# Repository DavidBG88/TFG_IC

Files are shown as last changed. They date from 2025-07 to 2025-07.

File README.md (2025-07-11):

# SIDCMOCS  
**Sistema Inteligente Distribuido de Control y Monitorización para la Optimización de Cultivos Sostenibles sobre una Arquitectura Edge-IoT basada en ESP32**

## Descripción

Este proyecto desarrolla **SIDCMOCS**, una solución modular y económica diseñada para automatizar el control climático de invernaderos mediante tecnologías abiertas. El sistema utiliza microcontroladores ESP32 en una arquitectura distribuida IoT para monitorizar variables ambientales y activar actuadores en función de las condiciones detectadas.

Entre sus funcionalidades destacan:

- Monitorización de temperatura, humedad, iluminación, calidad del aire y condiciones del suelo.
- Activación automática de ventiladores, luces LED y sistemas de riego.
- Comunicación distribuida mediante MQTT.
- Visualización remota con Grafana Cloud y alertas vía bot de Telegram.
- Almacenamiento local en tarjetas microSD y backend con Node.js y MySQL.
- Análisis de datos con Python y generación de gráficas.

El sistema ha sido validado mediante una maqueta funcional en un entorno doméstico controlado.

## Estructura del repositorio

- Codigo/ # Código fuente para ESP32 (C++), dividido en nodo maestro y esclavos, pruebas y scripts del backend

- Diagramas/ # Esquemas de arquitectura, montaje, etc

- Gastos.xlsx # Hoja de cálculo con presupuesto y materiales utilizados

- README.md # Archivo descriptivo del proyecto

## Tecnologías utilizadas

- **Hardware**: ESP32, sensores AHT10, ENS160, VEML7700, etc., actuadores (ventiladores, bombas, LEDs), panel solar, microSD
- **Firmware**: C++ (Arduino IDE, MQTT)
- **Backend**: Node.js, MySQL
- **Frontend**: Grafana Cloud (mediante Private Data Connection)
- **Otros**: Python (análisis de datos), Telegram Bot API, OpenWeatherMap API

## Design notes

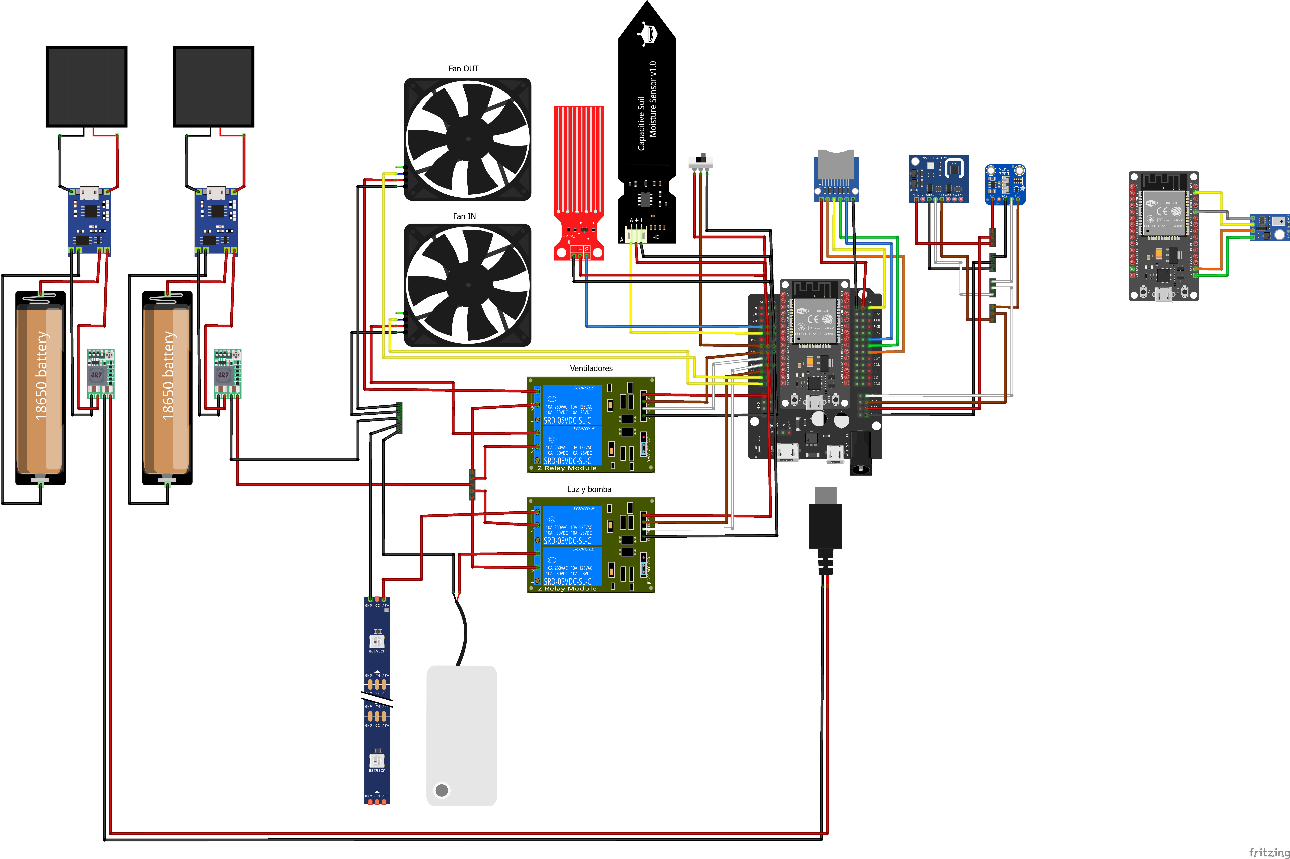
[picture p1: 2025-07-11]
Diagramas/Diseño_Fritzing.png

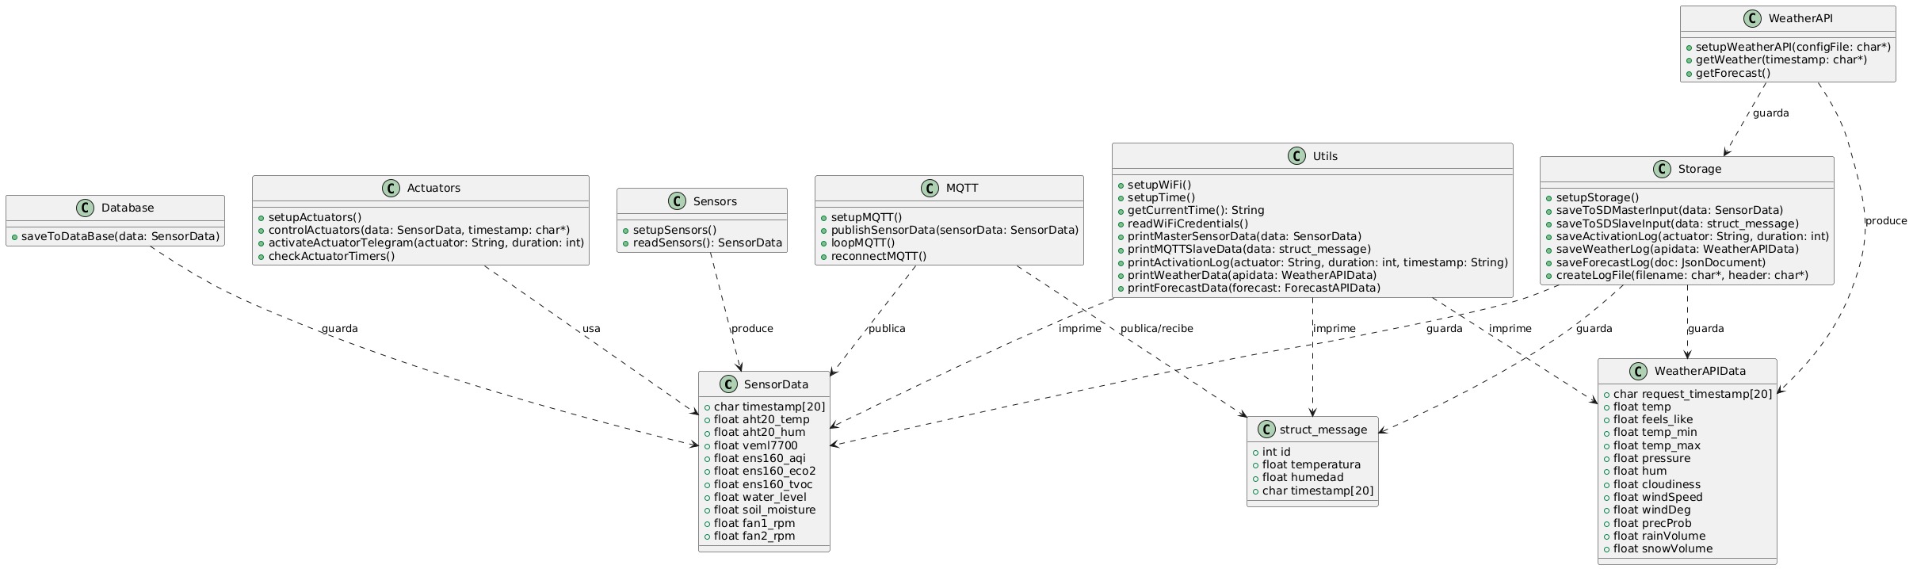
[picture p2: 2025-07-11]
Diagramas/Clases.png

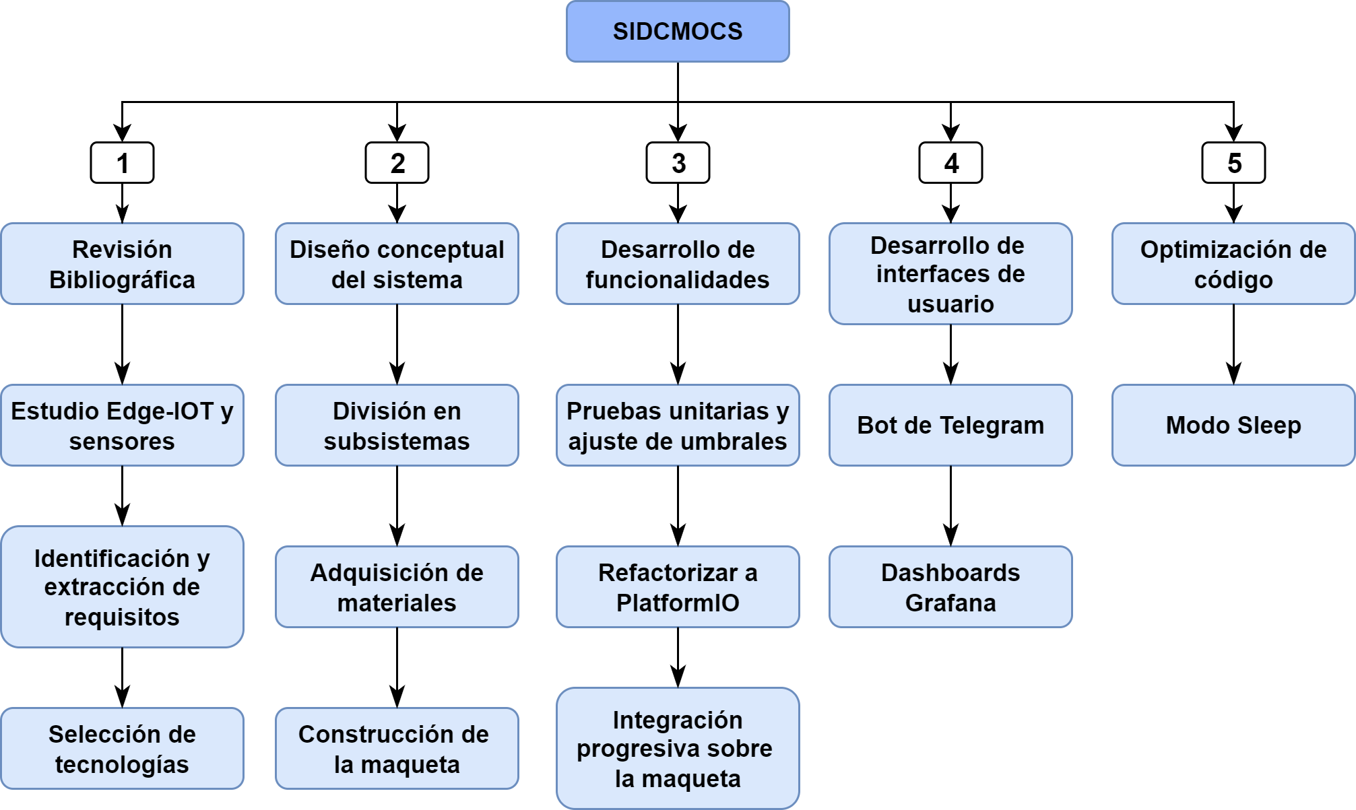
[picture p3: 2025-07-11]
Diagramas/Metodologia.png

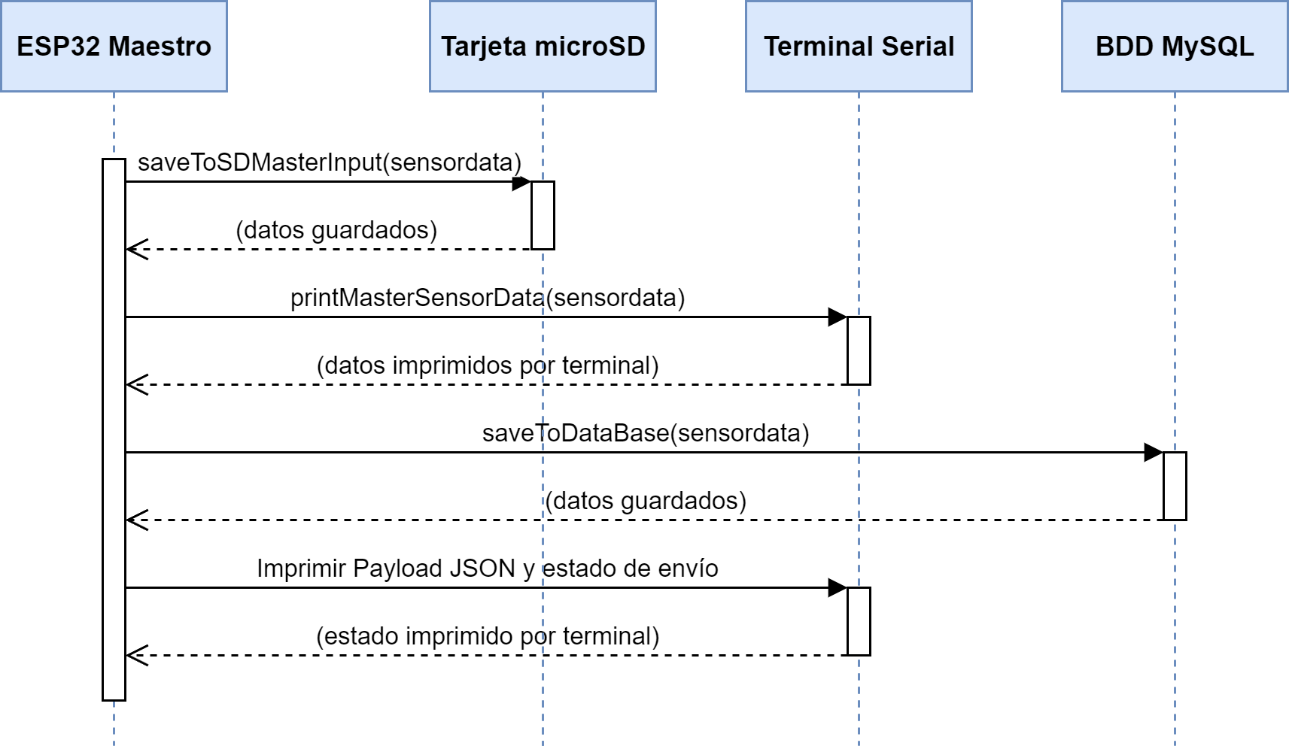
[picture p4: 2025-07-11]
Diagramas/Secuencia/Secuencia_guardadoDatos.png

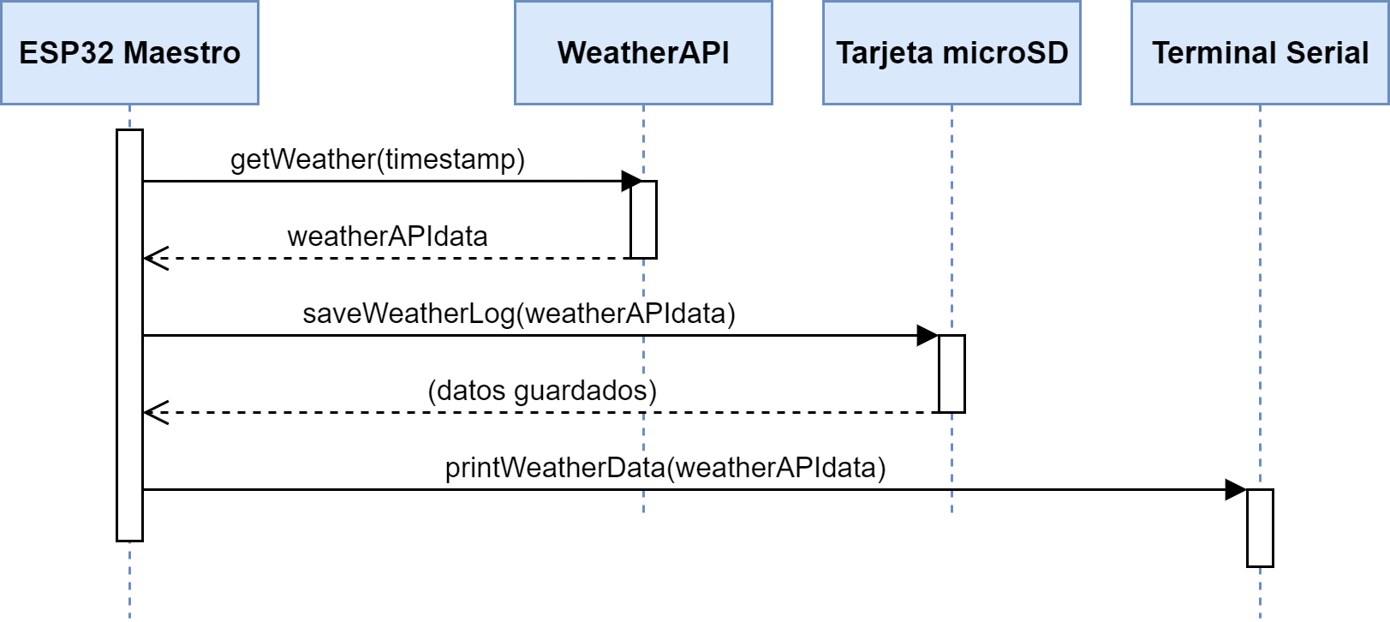
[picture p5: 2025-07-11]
Diagramas/Secuencia/Secuencia_API.png

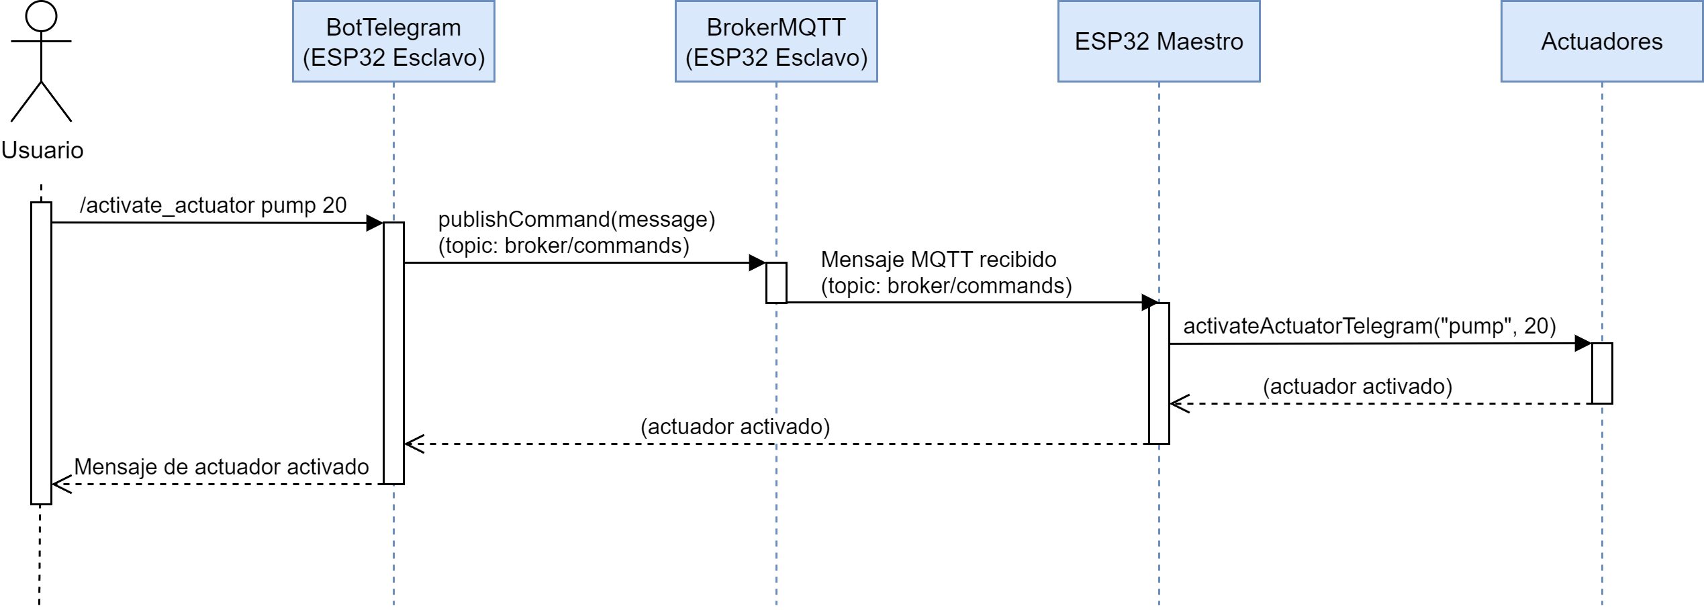
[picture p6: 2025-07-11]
Diagramas/Secuencia/Secuencia_activacionTelegram.png

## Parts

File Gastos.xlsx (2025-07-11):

MATERIALES VARIOS | LINK | REFERENCIA | 1 | UNIDADES | TOTAL
Bisagra |  |  | 1.2 | 1 | 1.2
Jardinera verde 38cm |  |  | 1.35 | 4 | 5.4
Tornillos 3x35 |  |  | 0.9 | 4 | 3.6
Tornillos 3x25 |  |  | 0.9 | 1 | 0.9
Tablero madera negro 70x50cm |  |  | 7.2 | 1 | 7.2
Caja componentes eléctricos |  |  | 4.9 | 1 | 4.9
Deposito agua 3.25L |  |  | 1.9 | 1 | 1.9
Cables dupont hembra-hembra | https://www.todoelectronica.com/cable-dupont-de-40-vias-20cm-hembra-hembra-con-hilo-de-cobre-p-110236.html |  | 108.0007 | 1 | 1.15
Kit 128 tubos termorretráctiles negros | https://www.todoelectronica.com/kit-de-128-tubos-termorretractiles-negros-con-medida-y-diametro-variados-p-116767.html |  | 161.250072 | 1 | 3.47
Plantas Viveros Sanchez | --- |  | --- | 1 | 10
MATERIALES LEROY MERLIN | LINK | REFERENCIA | PRECIO/UD | UNIDADES | TOTAL | TOTAL VARIOS
Semilla de perejil Común | https://www.leroymerlin.es/productos/jardin-y-terraza/plantas-semillas-y-arboles/semillas-de-huerta-flor-y-culinarias/semilla-de-perejil-comun-10490830.html | 10490830 | 1.49 | 1 | 1.49 | 39.72
Semilla de albahaca Grande Verde | https://www.leroymerlin.es/productos/jardin-y-terraza/plantas-semillas-y-arboles/semillas-de-huerta-flor-y-culinarias/semilla-de-albahaca-grande-verde-1049072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 | 10490725 | 1.49 | 1 | 1.49
Semilla de hierbabuena | https://www.leroymerlin.es/productos/jardin-y-terraza/plantas-semillas-y-arboles/semillas-de-huerta-flor-y-culinarias/hierbabuena-0-2g-90427463.html | 90427463 | 2.24 | 1 | 2.24 | TOTAL LEROY
Semilla de orégano Mejorana | https://www.leroymerlin.es/productos/jardin-y-terraza/plantas-semillas-y-arboles/semillas-de-huerta-flor-y-culinarias/semillas-de-oregano-mejorana-81905336.html | 81905336 | 1.19 | 1 | 1.19 | 48.15
Microtubo riego por goteo 4 mm 15 m | https://www.leroymerlin.es/productos/microtubo-para-riego-4mm-negro-de-15-m-90170896.html | 90170896 | 3.99 | 1 | 3.99
Pack 10 goteros Regulables | https://www.leroymerlin.es/productos/jardin-y-terraza/riego/ayuda-con-el-riego/riego-por-goteo-para-huerto/pack-10-goteros-regulables-0-60-l-h-geolia-83210897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 | 83210897 | 2.99 | 1 | 2.99 | TOTAL ALIEXPRESS
Pack 25 Te uniones | https://www.leroymerlin.es/productos/jardin-y-terraza/riego/riego-por-goteo/pack-25-te-6-mm-geolia-83211073.html | 83211073 | 4.29 | 1 | 4.29 | 55.35
Placa Policarbonato 2x1M | https://www.leroymerlin.es/productos/construccion/cubiertas-y-tejados/cubiertas-y-placas-policarbonato/panel-de-policarbonato-celular-plano-translucida-4mm-de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 | 10603054 | 12.29 | 1 | 12.29
Sustrato universal 20L | https://www.leroymerlin.es/productos/sustrato-universal-compo-sana-para-todo-tipo-de-plantas-interior-y-exterior-20l-258972.html | 258972 | 3.89 | 1 | 3.89 | TOTAL AMAZON
Pack 9 Listones Abeto | https://www.leroymerlin.es/productos/pack-de-9-listones-de-abeto-sin-cepillar-13x25x2000mm-ancho-x-espesor-x-largo-82137956.html | 82137956 | 14.29 | 1 | 14.29 | 45.56
 |  |  |  |  |  | TOTAL PROYECTO
MATERIALES ALIEXPRESS | LINK | REFERENCIA | PRECIO/UD | UNIDADES | TOTAL | 188.78
Tira de luces LED 5V - 1M Waterproof Warm White | https://es.aliexpress.com/item/32952790418.html | 32952790418 | 3.27 | 1 | 3.27
Mini Módulo de diodos LED de tráfico | https://es.aliexpress.com/item/1005006161998547.html | 1005006161998540 | 0.87 | 1 | 0.87
Cable de extensión de 2 pines - 20M | https://es.aliexpress.com/item/1005005565459721.html | 1005005565459720 | 3.96 | 1 | 3.96
Ventilador 80MM - 5V 3 pin | https://es.aliexpress.com/item/33022096969.html | 33022096969 | 3.9 | 2 | 7.8
Módulo de relé - 5V 2 way channel | https://es.aliexpress.com/item/1005005626475953.html | 1005005626475950 | 1.47 | 3 | 4.41
Módulo capacitivo sensor de humedad del suelo | https://es.aliexpress.com/item/1005003004790140.html | 1005003004790140 | 1.19 | 1 | 1.19
Cables macho a macho - 20cm 20 pin | https://es.aliexpress.com/item/1005006263457745.html | 1005006263457740 | 0.87 | 1 | 0.87
Cables macho a hembra - 20cm 20 pin | https://es.aliexpress.com/item/1005006263457745.html | 1005006263457740 | 0.83 | 1 | 0.83
Cables hembra a hembra - 20cm 20 pin | https://es.aliexpress.com/item/1005006263457745.html | 1005006263457740 | 0.85 | 1 | 0.85
Módulo de expansión de almacenamiento microSD | https://es.aliexpress.com/item/1005005591145849.html | 1005005591145840 | 0.88 | 1 | 0.88
Bomba de motor sumergible - Amphibious Type | https://es.aliexpress.com/item/32869484514.html | 32869484514 | 2 | 1 | 2
Sensor calidad aire, temperatura y humedad - ENS160+AHT20 | https://es.aliexpress.com/item/1005006125242045.html | 1005006125242040 | 0.99 | 1 | 0.99
Módulo de sensor de luz ambiental - VEML7700 | https://es.aliexpress.com/item/1005004926993351.html | 1005004926993350 | 2.42 | 1 | 2.42
Módulo de sensor de nivel de agua analógico | https://es.aliexpress.com/item/1005006389574525.html | 1005006389574520 | 0.57 | 1 | 0.57
Módulo de sensor de temperatura y humedad - AHT10 | https://es.aliexpress.com/item/1005005630775595.html | 1005005630775590 | 0.96 | 2 | 1.92
Panel Solar 6W 6V | https://es.aliexpress.com/item/1005007955979899.html | 1005007955979899 | 4.39 | 2 | 8.78
Conversor CC CC | https://es.aliexpress.com/item/1005007013856492.html | 1005007013856490 | 0.93 | 2 | 1.86
Placa de pruebas horizontal | https://es.aliexpress.com/item/1005006990183423.html | 1005006990183423 | 1.77 | 1 | 1.77
Conectores macho DC | https://es.aliexpress.com/item/1005005827656117.html | 1005005827656117 | 1.5 | 1 | 1.5
Módulo de carga batería 18650 - MCP73871 | https://es.aliexpress.com/item/1005006864225593.html | 1005006864225593 | 2.58 | 2 | 5.16
Placa de expansión ESP32 | https://es.aliexpress.com/item/1005006124044428.html | 1005006124044420 | 1.79 | 1 | 1.79
Módulo indicador capacidad batería litio | https://es.aliexpress.com/item/1005005968856522.html | 1005005968856522 | 0.8 | 1 | 0.8
Soporte batería 18650 (3 uds) | https://es.aliexpress.com/item/1005006283625827.html | 1005006283625820 | 0.86 | 1 | 0.86
 |  |  |  |  | 0
 |  |  |  |  | 0
MATERIALES AMAZON | LINK | REFERENCIA | PRECIO/UD | UNIDADES | TOTAL
Placa de desarrollo ESP32 NodeMCU | https://www.amazon.es/dp/B0DGLCWR76/ | B0DGLCWR76 | 6 | 3 | 18
Batería litio 18650 2500mAh 3,7v | https://www.amazon.es/dp/B0D6ZWTSD7 | B0D6ZWTSD7 | 9.5 | 2 | 19
Tarjeta MicroSD 32GB SanDisk | https://www.amazon.es/dp/B08GY9NYRM/ | B08GY9NYRM | 8.56 | 1 | 8.56

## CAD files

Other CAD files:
Modelo.blend

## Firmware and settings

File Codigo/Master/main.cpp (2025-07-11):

#include <Arduino.h>

#include "sensors.h"
#include "actuators.h"
#include "storage.h"
#include "weatherapi.h"
#include "mode.h"
#include "time.h"
#include "mqtt.h"
#include "esp32_zip.h"
#include "driver/rtc_io.h"

void setup() {
    Serial.begin(115200);

    // Libera el pin del modo RTC IO (Deep Sleep)
    rtc_gpio_deinit((gpio_num_t)33);

    // Configurar el pin del interruptor
    pinMode(switchPin, INPUT);

    // Inicializar la tarjeta SD y crear archivos necesarios si no existen
    setupStorage();

    // Configurar la conexión WiFi
    setupWiFi();

    // Configura el reloj y sincroniza la hora con un servidor NTP
    setupTime();

    // Inicializa y configura los sensores conectados
    setupSensors();

    // Configura los actuadores para su control
    setupActuators();

    // Configura la API del clima, leyendo datos de configuración desde un archivo en la SD
    setupWeatherAPI("/config.txt");

    // Configura MQTT para la comunicación
    setupMQTT();  // Iniciar la conexión MQTT y las suscripciones
}

void loop() {
    // Verificar si el interruptor ha cambiado y actualizar el modo del sistema
    checkSwitch();

    // Ejecutar la operación según el modo actual del sistema -> true = Modo predefinido, false = Modo sleep
    if (systemMode) {
        modePredefinedOperation();  // Modo predefinido
    } else {
        sleepMode();  // Modo sleep para ahorro de energía
    }

    // Mantener la conexión MQTT activa
    loopMQTT();
}

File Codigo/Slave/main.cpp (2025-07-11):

#include <Arduino.h>
#include "mqtt.h"
#include "telegrambot.h"
#include "aht10.h"
#include <EEPROM.h>

// Intervalo de tiempo para lecturas del sensor (1 minuto)
unsigned long lastSensorRead = 0;

// Zona horaria y servidores NTP para España
const char* ntpServer0 = "0.es.pool.ntp.org";
const char* ntpServer1 = "1.es.pool.ntp.org";
const char* ntpServer2 = "2.es.pool.ntp.org";
const long gmtOffset_sec = 3600;        // Offset de GMT para España (GMT+1)
const int daylightOffset_sec = 3600;    // Horario de verano

void setupTime() {
    for (int i = 0; i < 5; i++) { // Reintenta hasta 5 veces
        configTime(gmtOffset_sec, daylightOffset_sec, ntpServer0, ntpServer1, ntpServer2);
        delay(2000);
        struct tm timeinfo;
        if (getLocalTime(&timeinfo)) {
            Serial.println("Hora obtenida con exito");
            return;
        }
        Serial.println("Error al obtener la hora, reintentando...");
    }
    Serial.println("No se pudo obtener la hora despues de varios intentos");
}

void setup() {
    Serial.begin(115200);

    // Inicializar el sensor AHT10
    setupSensor();

    // Configurar y arrancar MQTT
    setupMQTT();

    // Configurar la sincronización de tiempo NTP
    setupTime();

    // Configurar y arrancar el bot de Telegram
    setupTelegramBot();
}

void loop() {
    static unsigned long lastUpdate = 0;
    unsigned long currentMillis = millis();
    struct tm timeinfo;
    char timestamp[20];

    // Verificar y manejar las interacciones del bot de Telegram cada 2 segundos
    if (currentMillis - lastUpdate > 2000) {
        checkTelegramUpdates();
        lastUpdate = currentMillis;
    }

    // Sincronizar la lectura del sensor entre los segundos 0 y 5 del minuto
    if (getLocalTime(&timeinfo)) {
        int currentSecond = timeinfo.tm_sec;
        int currentMinute = timeinfo.tm_min;

        // Verificar si estamos en los primeros 5 segundos del minuto
        if (currentSecond >= 0 && currentSecond <= 5) {
            // Verificar que no hemos hecho ya una lectura en este minuto
            if (lastSensorRead != currentMinute) {
                // Formatear el timestamp con segundos 00
                strftime(timestamp, sizeof(timestamp), "%H:%M:%S %d/%m/%Y", &timeinfo);

                // Ajustar el timestamp para asegurar que siempre tenga "00" segundos
                strncpy(&timestamp[6], "00", 2);

                // Leer datos del sensor AHT10 y publicar los datos vía MQTT
                struct_message sensorData = readSensor(timestamp);

                publishSensorData(sensorData);

                // Actualizar la marca de tiempo del último minuto de lectura
                lastSensorRead = currentMinute;
            }
        }
    } else {
        Serial.println("Error al obtener la hora");
    }

    // Mantener la conexión MQTT
    loopMQTT();
}

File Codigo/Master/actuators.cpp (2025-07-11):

#include "actuators.h"
#include "sensors.h"
#include "storage.h"
#include <Arduino.h>

// Pines de los actuadores
const int ledPin = 27;    // GPIO para luces
const int fanInputPin = 25; // GPIO para ventilador de entrada
const int fanOutputPin = 26; // GPIO para ventilador de salida
const int pumpPin = 14;   // GPIO para la bomba de riego
const int fan1 = 12;  // Pin del ventilador 1
const int fan2 = 13;  // Pin del ventilador 2

volatile int pulseCount1 = 0;
volatile int pulseCount2 = 0;

void IRAM_ATTR onTachPulse1() {
    pulseCount1++;
}

void IRAM_ATTR onTachPulse2() {
    pulseCount2++;
}

// Variables para controlar el tiempo de activación
unsigned long pumpStartTime = 0;
unsigned long fanStartTime = 0;
unsigned long lightStartTime = 0;
unsigned long pumpTelegramStartTime = 0;
unsigned long fanTelegramStartTime = 0;
unsigned long lightTelegramStartTime = 0;

bool ledActive = false;
bool pumpActive = false;
bool fanActive = false;

// Duraciones preestablecidas
const unsigned long pumpDuration = 20000;  // Duración máxima de riego en milisegundos
const unsigned long fanDuration = 300000;  // Duración máxima de ventilación en milisegundos (5 minutos)
const unsigned long lightDuration = 300000; // Duración máxima de iluminación en milisegundos (5 minutos)

// Umbrales preestablecidos
float lightThreshold = 1000;
float waterLevelThreshold = 30;
float soilMoistureThreshold = 30;
float co2Threshold = 500;
float aqiThreshold = 2;
float tempThreshold = 27.0;

void setupActuators() {
    pinMode(ledPin, OUTPUT);
    pinMode(fanInputPin, OUTPUT);
    pinMode(fanOutputPin, OUTPUT);
    pinMode(pumpPin, OUTPUT);
    pinMode(fan1, INPUT_PULLUP);
    pinMode(fan2, INPUT_PULLUP);

    attachInterrupt(digitalPinToInterrupt(fan1), onTachPulse1, FALLING);
    attachInterrupt(digitalPinToInterrupt(fan2), onTachPulse2, FALLING);

    // Inicializar los actuadores apagados
    digitalWrite(ledPin, HIGH);
    digitalWrite(fanInputPin, HIGH);
    digitalWrite(fanOutputPin, HIGH);
    digitalWrite(pumpPin, HIGH);
}

void controlActuators(SensorData& data, const char* timestamp) {
    // Extraer la hora del timestamp usando funciones de C estándar
    char hourStr[3] = { timestamp[0], timestamp[1], '\0' };
    int hour = atoi(hourStr);

    // Control de luces
    if (data.veml7700 < lightThreshold && (hour >= 6 && hour < 22)) {
        digitalWrite(ledPin, LOW);  // Encender luz
        ledActive = true;
        lightStartTime = millis();  // Actualizar tiempo de inicio
        saveActivationLog("light", lightDuration / 1000);
        Serial.println("Luz encendida y datos guardados en SD");
    } else if (hour < 6 || hour >= 22) {
        digitalWrite(ledPin, HIGH); // Apagar luz por fuera del horario permitido
        Serial.println("Luz apagada por estar fuera del horario permitido");
    } else {
        digitalWrite(ledPin, HIGH); // Apagar luz por suficiente luz
        Serial.println("Luz apagada por suficiente luz");
    }

    // Control del sistema de riego
    if (data.water_level > waterLevelThreshold && data.soil_moisture < soilMoistureThreshold) {
        digitalWrite(pumpPin, LOW);  // Encender bomba
        pumpActive = true;
        pumpStartTime = millis();  // Actualizar tiempo de inicio
        saveActivationLog("pump", pumpDuration / 1000);
        Serial.println("Bomba de riego activada y datos guardados en SD");
    } 

    // Control de ventiladores
    if (data.ens160_aqi >= aqiThreshold || data.ens160_eco2 > co2Threshold || data.aht20_temp >= tempThreshold) {
        digitalWrite(fanInputPin, LOW);  // Encender ventilador de entrada
        digitalWrite(fanOutputPin, LOW); // Encender ventilador de salida
        fanActive = true;
        fanStartTime = millis();  // Actualizar tiempo de inicio
        saveActivationLog("fan", fanDuration / 1000);
        Serial.println("Ventiladores activados y datos guardados en SD");
    }

    // Cálculo de RPM para ventiladores
    noInterrupts();  
    int pulses1 = pulseCount1;
    int pulses2 = pulseCount2;
    pulseCount1 = 0;
    pulseCount2 = 0;
    interrupts();  

    data.fan1_rpm = (pulses1 * 60.0) / (2.0 * 10.0);
    data.fan2_rpm = (pulses2 * 60.0) / (2.0 * 10.0);
}

void checkActuatorTimers() {
    // Verificación de luces
    if (ledActive && millis() - lightStartTime >= lightDuration) {
        digitalWrite(ledPin, HIGH);
        ledActive = false;
        Serial.println("Luz apagada despues de la activacion por sensor");
    }

    // Verificacion de bomba
    if (pumpActive && millis() - pumpStartTime >= pumpDuration) {
        digitalWrite(pumpPin, HIGH);
        pumpActive = false;
        Serial.println("Bomba apagada despues de la activacion por sensor");
    }

    // Verificación de ventiladores
    if (fanActive && millis() - fanStartTime >= fanDuration) {
        digitalWrite(fanInputPin, HIGH);
        digitalWrite(fanOutputPin, HIGH);
        fanActive = false;
        Serial.println("Ventiladores apagados despues de la activacion por sensor");
    }
}
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

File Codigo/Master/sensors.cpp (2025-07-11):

#include "sensors.h"
#include <Adafruit_VEML7700.h>
#include <Adafruit_AHTX0.h>
#include "ScioSense_ENS160.h"
#include <Arduino.h>
#include <Wire.h>
#include "time.h"
#include "storage.h"

// Definir los pines de los sensores
#define WATER_LEVEL_PIN 34  // Pin ADC1_CH6
#define SOIL_MOISTURE_PIN 35 // Pin ADC1_CH7

// Dirección I2C del ENS160 configurada según el pin ADD
#define ENS160_I2C_ADDRESS 0x53

// Definir los pines I2C para ESP32
#define SDA_PIN 21
#define SCL_PIN 22

const int water_AirValue = 0;   // Valor del sensor de nivel de agua en aire
const int water_WaterValue = 620;  // Valor del sensor de nivel de agua sumergido al completo
const int soil_AirValue = 2600;   // Valor del sensor de humedad del terreno en aire
const int soil_WaterValue = 1100;  // Valor del sensor de humedad del terreno en agua

// Definición de la variable global sensordata, que almacena los datos de los sensores
SensorData sensordata;

// Crear instancias de sensores
Adafruit_AHTX0 aht;
Adafruit_VEML7700 veml = Adafruit_VEML7700();
ScioSense_ENS160 ens160(ENS160_I2CADDR_0);

void setupSensors() {
    // Inicializar bus I2C
    Wire.begin(SDA_PIN, SCL_PIN);

    // Inicializar AHT10/AHT20
    int retryCount = 0;
    while (!aht.begin() && retryCount < 5) {
        Serial.println("No se pudo inicializar AHT20, reintentando...");
        delay(1000);
        retryCount++;
    }
    if (retryCount == 5) {
        Serial.println("Fallo critico: No se pudo inicializar AHT20.");
    } else {
        Serial.println("Sensor AHT20 inicializado");
    }

    // Retraso para asegurar que el bus I2C esté estable
    delay(100);

    // Inicializar ENS160
    retryCount = 0;  // Reiniciar el contador de reintentos
    while (!ens160.begin() && retryCount < 5) {
        Serial.println("No se pudo inicializar ENS160, reintentando...");
        delay(1000);
        retryCount++;
    }
    if (retryCount == 5) {
        Serial.println("Fallo critico: No se pudo inicializar ENS160.");
    } else {
        Serial.println("Sensor ENS160 inicializado");
        Serial.print("\tRev: ");
        Serial.print(ens160.getMajorRev());
        Serial.print(".");
        Serial.print(ens160.getMinorRev());
        Serial.print(".");
        Serial.println(ens160.getBuild());
    
        Serial.print("\tStandard mode ");
        if (ens160.setMode(ENS160_OPMODE_STD)) {
            Serial.println("done.");
        } else {
            Serial.println("failed!");
        }
    }

    // Inicializar VEML7700
    retryCount = 0;
    while (!veml.begin() && retryCount < 5) {
        Serial.println("No se pudo inicializar VEML7700, reintentando...");
        delay(1000);
        retryCount++;
    }
    if (retryCount == 5) {
        Serial.println("Fallo crítico: No se pudo inicializar VEML7700");
    } else {
        Serial.println("Sensor VEML7700 inicializado\n");
    }
    
    // Configurar pines de los sensores analógicos
    pinMode(WATER_LEVEL_PIN, INPUT);
    pinMode(SOIL_MOISTURE_PIN, INPUT);
}

SensorData readSensors() {

    // Asignar el timestamp de forma segura
    String currentTime = getCurrentTime();  // Obtener la fecha y hora actuales
    strncpy(sensordata.timestamp, currentTime.c_str(), sizeof(sensordata.timestamp) - 1);
    sensordata.timestamp[sizeof(sensordata.timestamp) - 1] = '\0';  // Asegurar el terminador nulo

    sensors_event_t humidity, temp;
    if (aht.getEvent(&humidity, &temp)) {
        sensordata.aht20_temp = temp.temperature;
        sensordata.aht20_hum = humidity.relative_humidity;
    } else {
        // Suponer valores normales si el sensor falla
        sensordata.aht20_temp = 25.0;
        sensordata.aht20_hum = 50.0;
    }

    sensordata.veml7700 = veml.readLux();  // Leer luz ambiente

    if (ens160.available()) {
        ens160.measure(true); // Iniciar medición del ENS160
        ens160.measureRaw(true); // Medición RAW
        sensordata.ens160_aqi = ens160.getAQI();
        sensordata.ens160_eco2 = ens160.geteCO2();
        sensordata.ens160_tvoc = ens160.getTVOC();
    } else {
        // Suponer valores normales si el sensor falla
        sensordata.ens160_aqi = 0;
        sensordata.ens160_eco2 = 400;
        sensordata.ens160_tvoc = 0;
    }

    // Leer y mapear a porcentaje el nivel de agua
    sensordata.water_level = analogRead(WATER_LEVEL_PIN); 
    sensordata.water_level = map(sensordata.water_level, water_AirValue, water_WaterValue, 0, 100);

    // Asegurar que el valor mapeado esté dentro de 0-100%
    sensordata.water_level = constrain(sensordata.water_level, 0, 100);

    // Leer y mapear a porcentaje la humedad del terreno
    sensordata.soil_moisture = analogRead(SOIL_MOISTURE_PIN);
    sensordata.soil_moisture = map(sensordata.soil_moisture, soil_AirValue, soil_WaterValue, 0, 100);

    // Asegurar que el valor mapeado esté dentro de 0-100%
    sensordata.soil_moisture = constrain(sensordata.soil_moisture, 0, 100);
    
    return sensordata;
}

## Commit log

2024-04-24 Added several files for ANTEPROYECTO
    [Modelo.blend]
2024-06-09 add frizting files and arduino tests
    [Proyecto.fzz, Water_sensor.fzz, data.csv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]
2024-06-09 add gastos xlsx
    [Gastos.xlsx]
2025-07-11 Final files upload
    [Gastos.xlsx, Modelo.blend, Planificacion_Gantt.xlsx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]
